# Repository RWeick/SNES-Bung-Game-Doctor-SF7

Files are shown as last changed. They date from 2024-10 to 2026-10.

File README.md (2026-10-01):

# SNES-Bung-Game-Doctor-SF7
The Kicad files and rom for the Bung Game Doctor SF7 for the SNES

This board has been tested and confirmed.
**30 Sep 2026: Thank you to CoolChecker for discovering that somehow a net failed to be connected - TC was not routed from the ASIC to the Floppy Controller. This has now been corrected.

Mainboard PCB Thickness: 1.6 mm
RAM PCB Thicknesses: 1.2 mm
SNES Attachment PCB Thickness: 1.2 mm

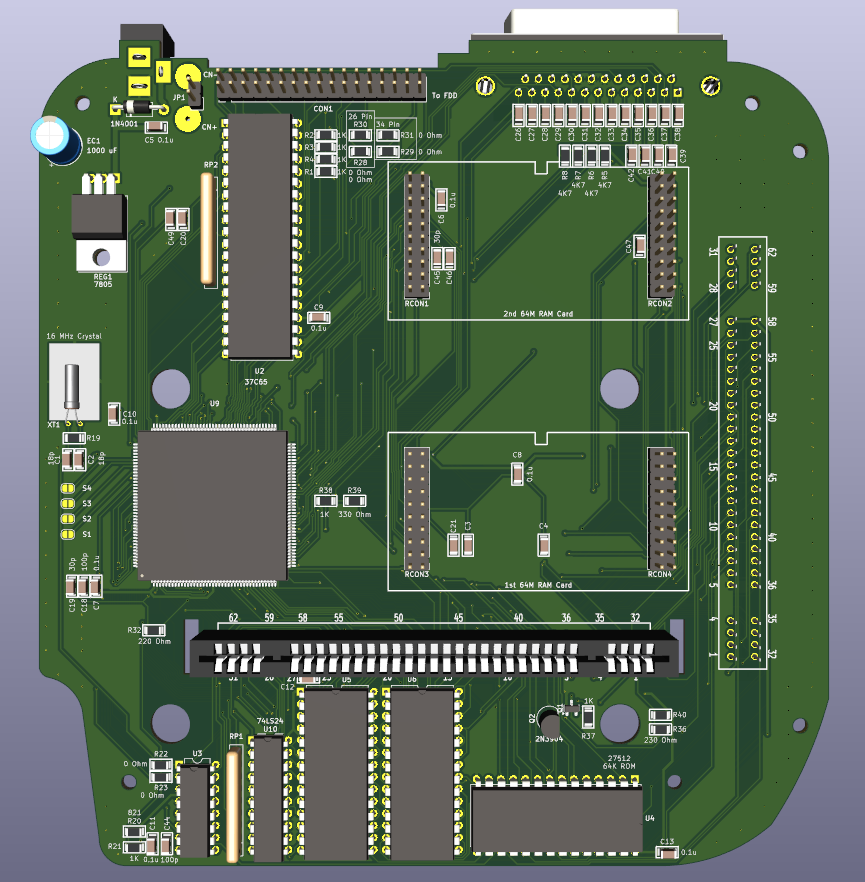
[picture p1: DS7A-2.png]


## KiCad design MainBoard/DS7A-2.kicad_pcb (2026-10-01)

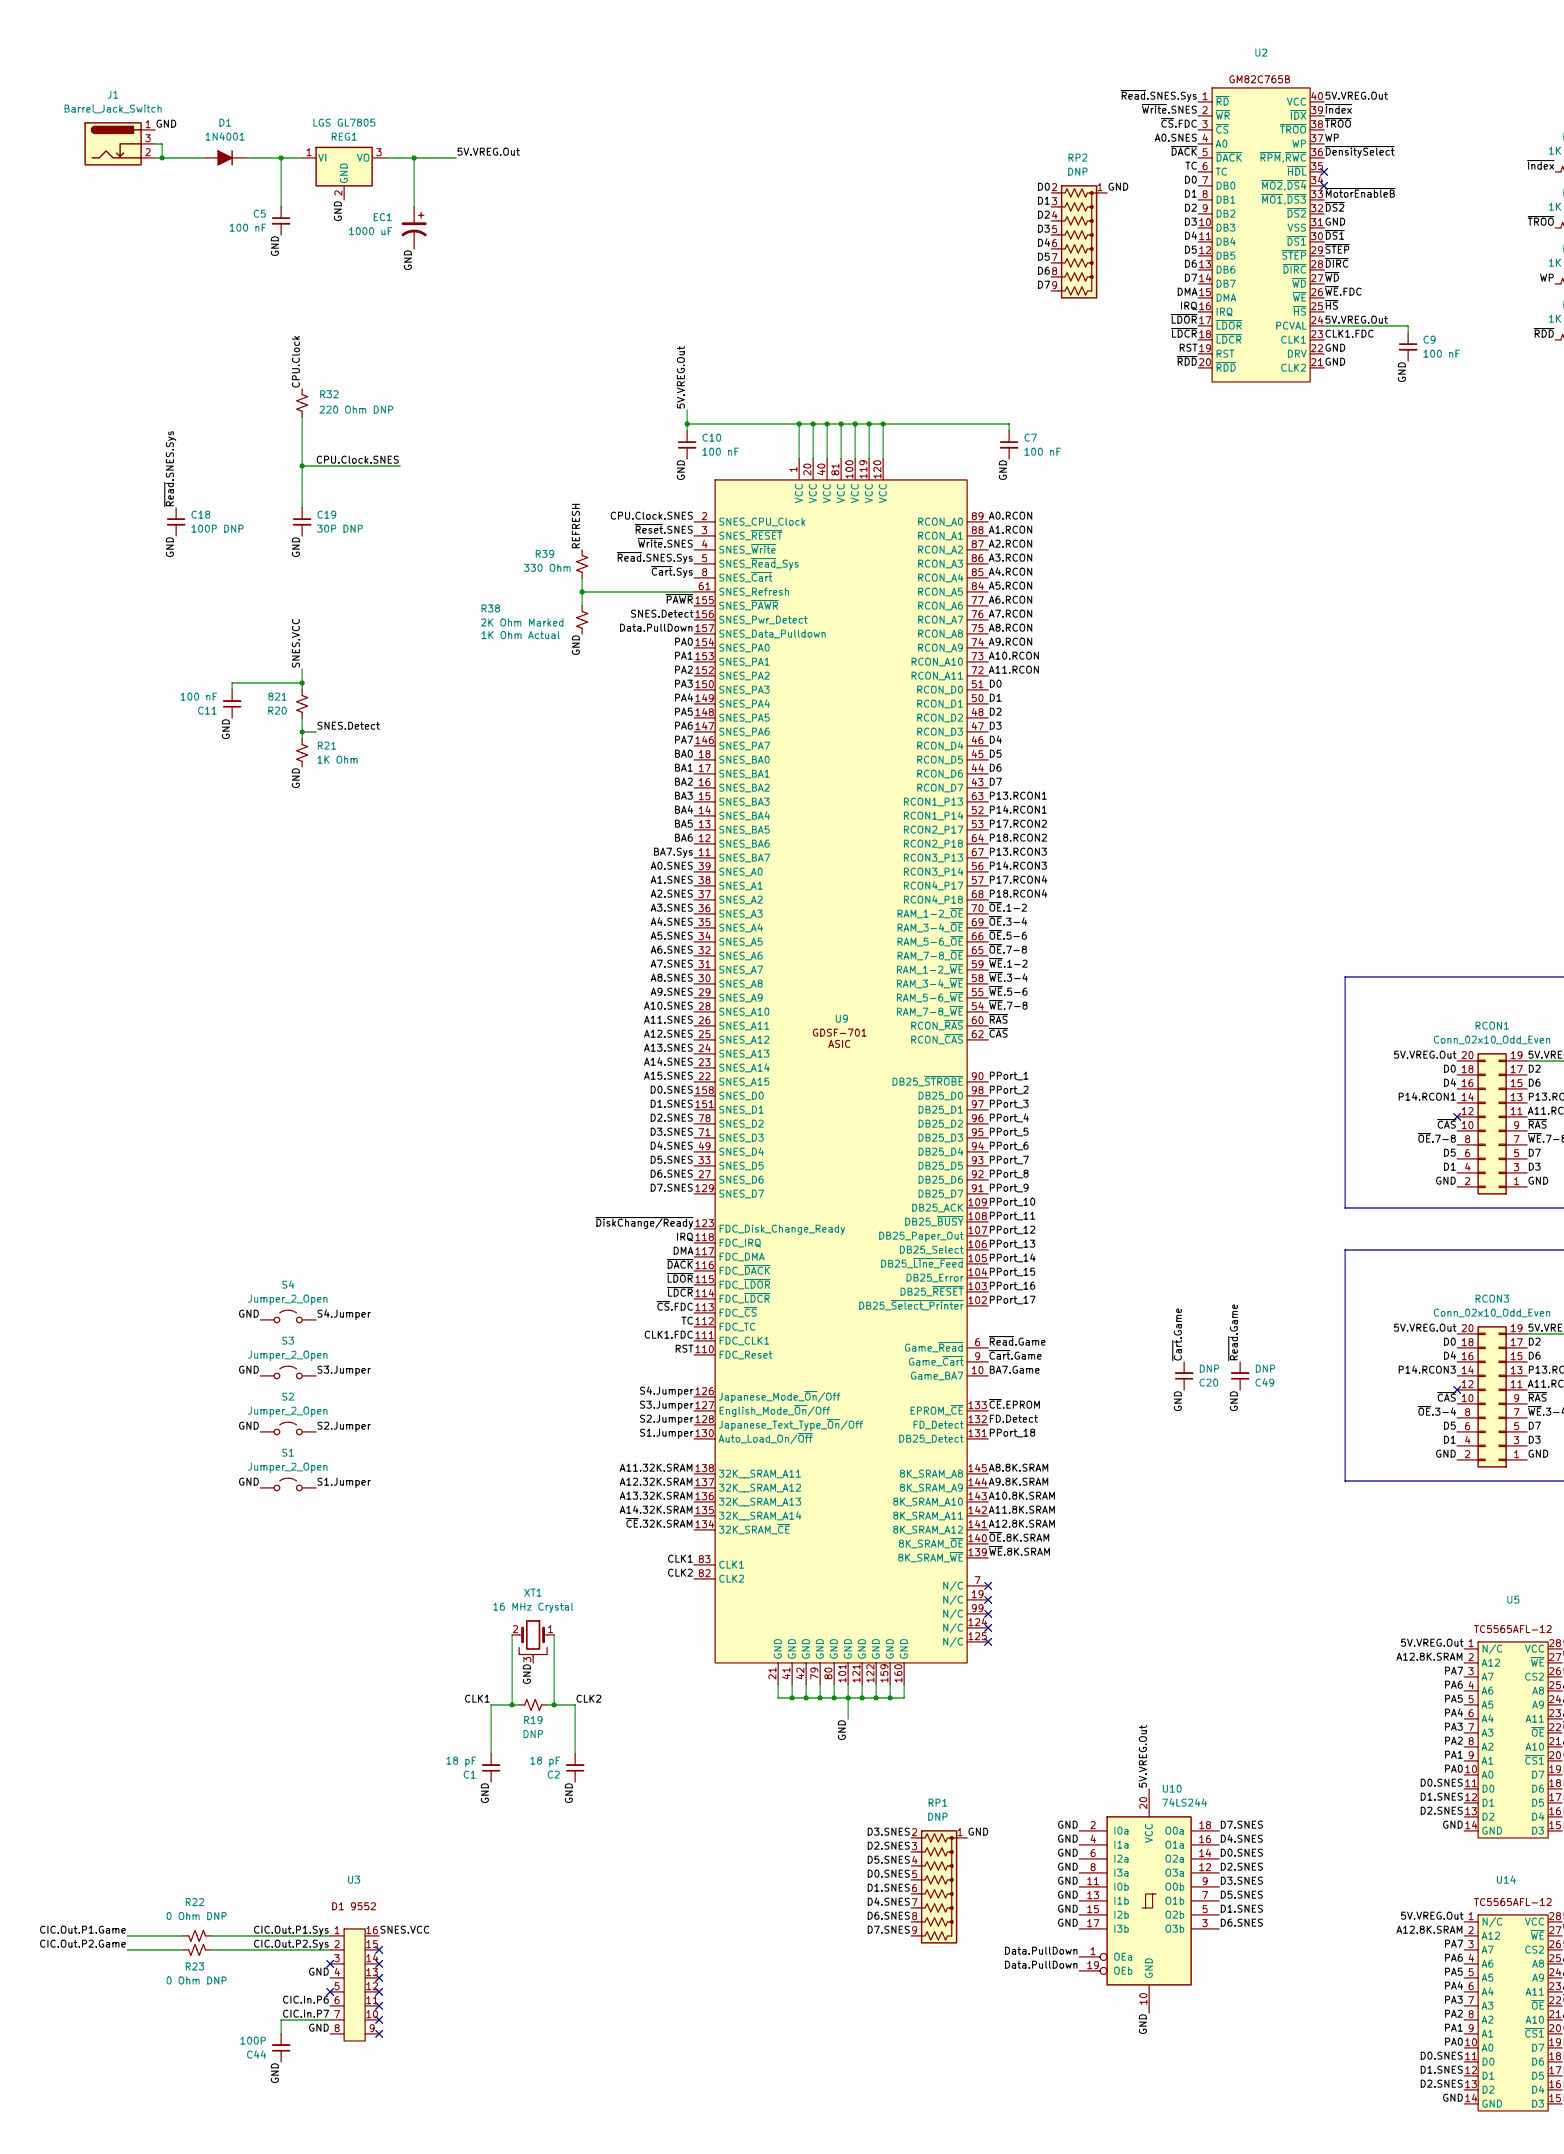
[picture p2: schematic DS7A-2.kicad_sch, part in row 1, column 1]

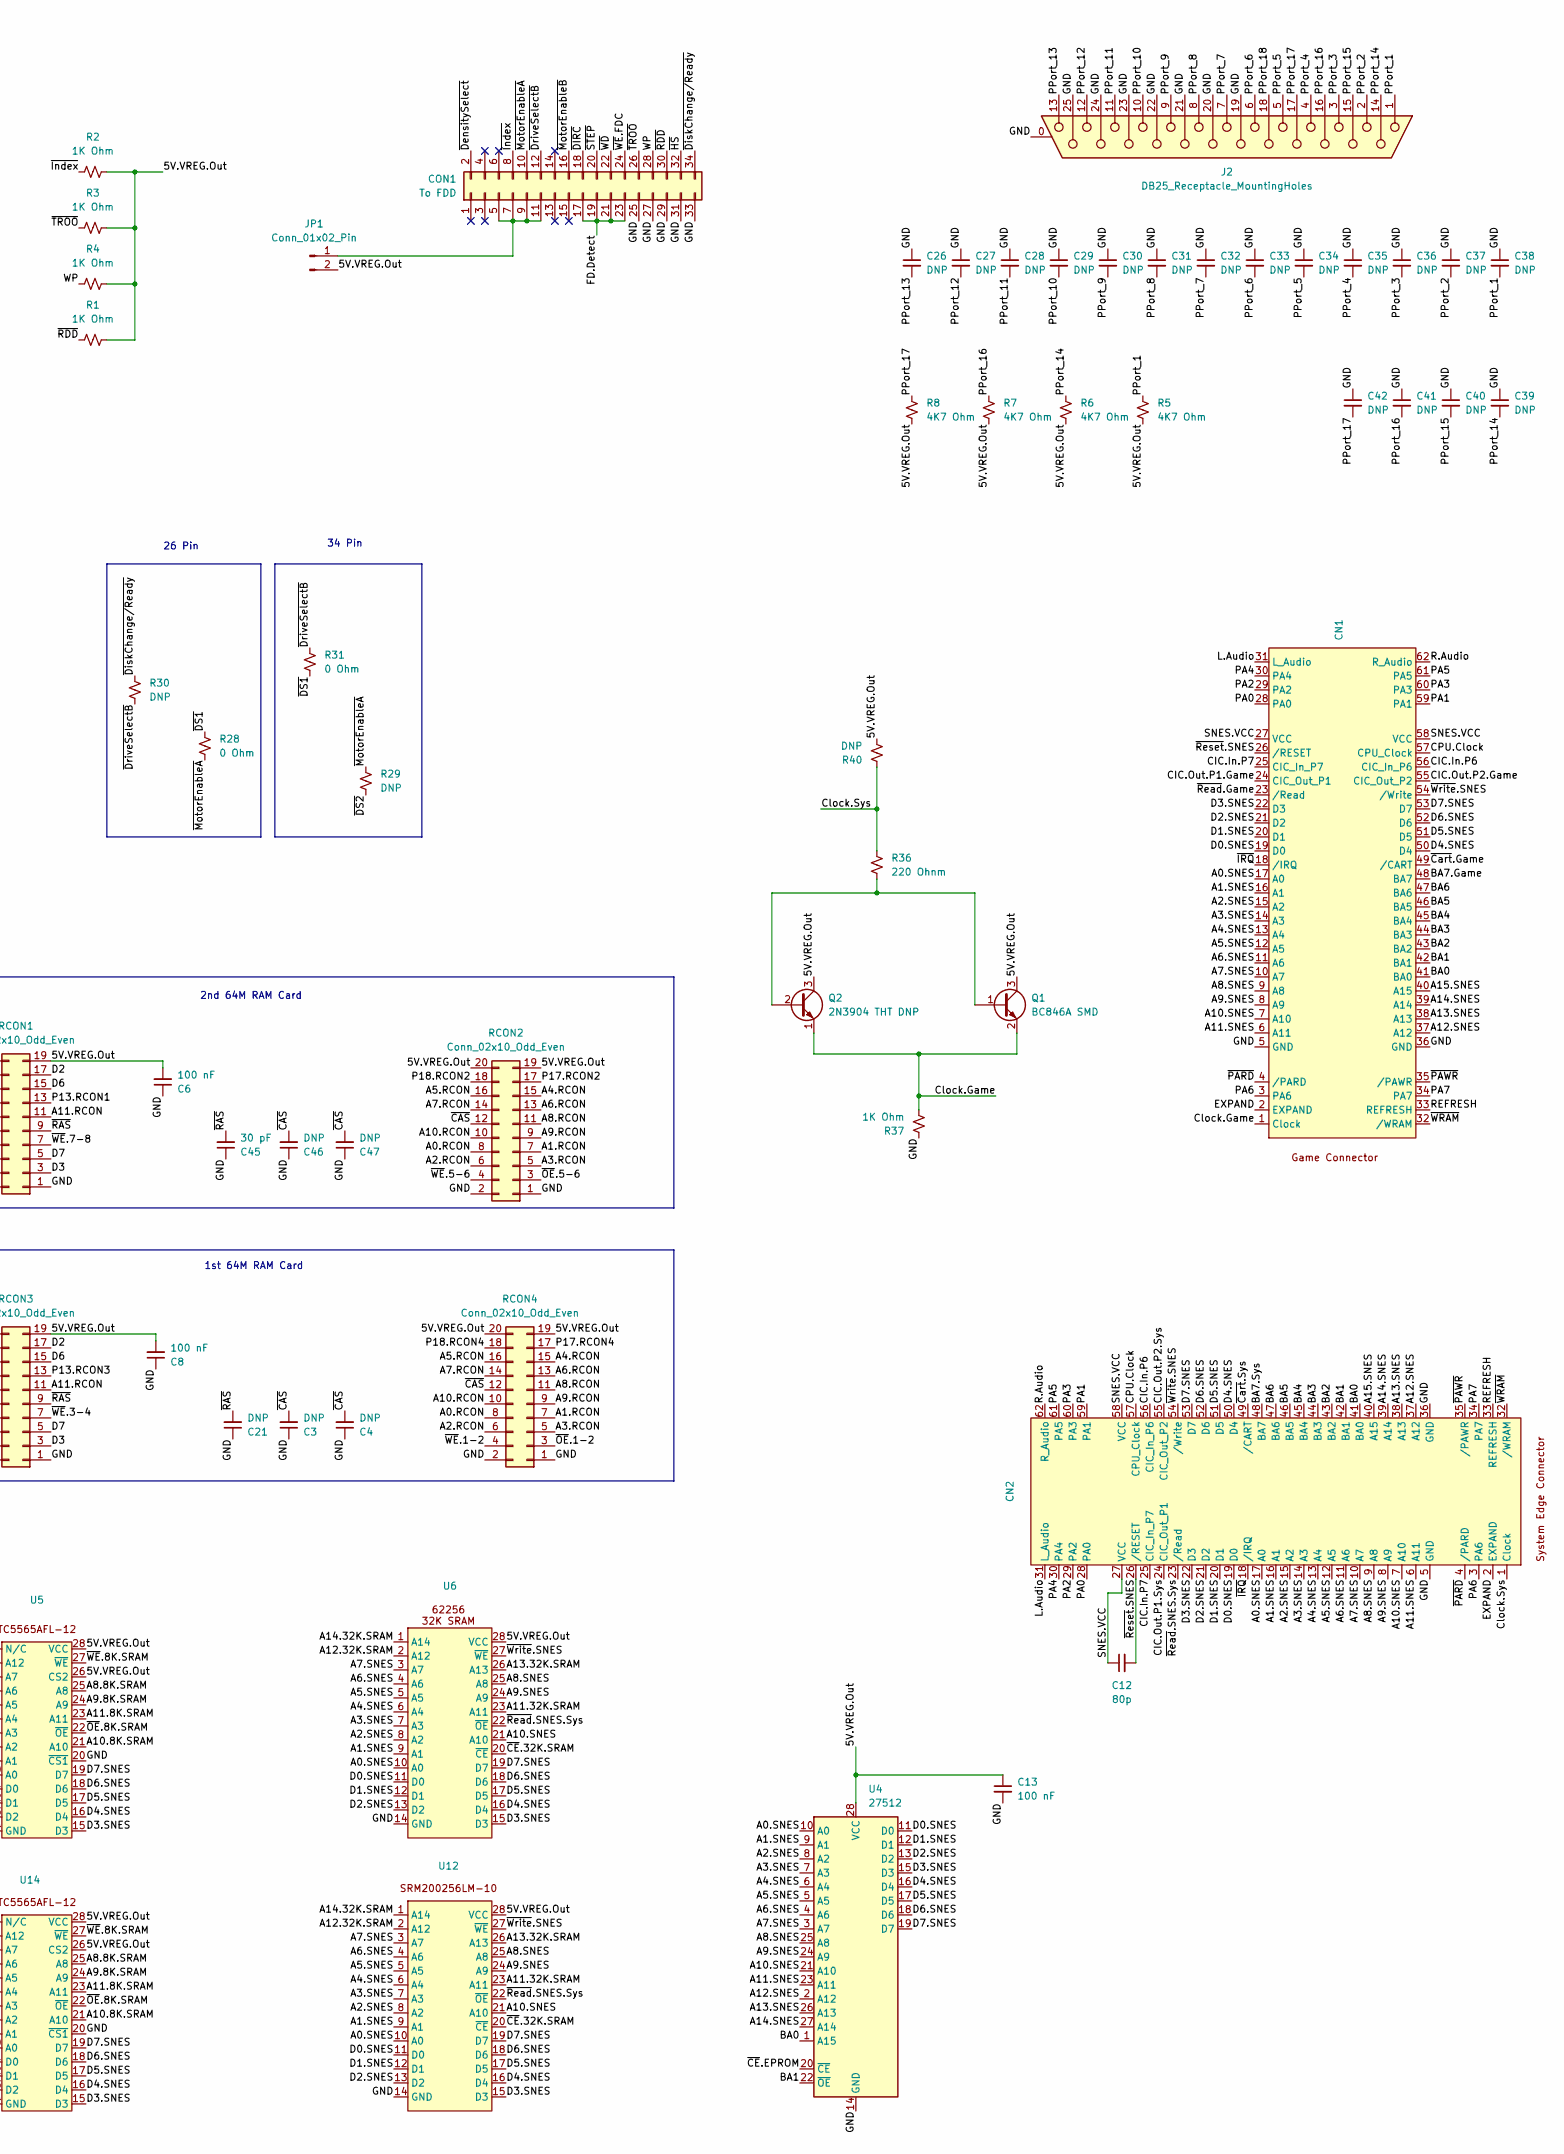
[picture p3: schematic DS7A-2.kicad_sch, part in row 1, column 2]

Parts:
C1, C2: 18 pF; SMD Cap
C3, C4, C20, C21, C26, C27, C28, C29, C30, C31, C32, C33, C34, C35, C36, C37, C38, C39, C40, C41, C42, C46, C47, C49: DNP; SMD Cap
C5, C6, C7, C8, C9, C10, C11, C13: 100 nF; SMD Cap
C12: 80p; SMD Cap
C18: 100P DNP; SMD Cap
C19: 30P DNP; SMD Cap
C44: 100P; SMD Cap
C45: 30 pF; SMD Cap
CN1, CN2: Cartridge Slot
CON1: To FDD; PinSocket_2x17_P2.54mm_Vertical
D1: 1N4001; D_DO-41_SOD81_P10.16mm_Horizontal
EC1: 1000 uF; CP_Radial_D8.0mm_P3.50mm
J1: Barrel_Jack_Switch; DC Jack
J2: DB25_Receptacle_MountingHoles; DSUB-25_Female_Horizontal_P2.77x2.84mm_EdgePinOffset9.90mm_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
JP1: Conn_01x02_Pin; PinHeader_1x02_P2.54mm_Vertical
Q1: BC846A SMD; SOT-23
Q2: 2N3904 THT DNP; TO-92_Inline
R1, R2, R3, R4, R21, R37: 1K Ohm; SMD Resistor
R5, R6, R7, R8: 4K7 Ohm; SMD Resistor
R19, R29, R30, R40: DNP; SMD Resistor
R20: 821; SMD Resistor
R22, R23: 0 Ohm DNP; SMD Resistor
R28, R31: 0 Ohm; SMD Resistor
R32: 220 Ohm DNP; SMD Resistor
R36: 220 Ohnm; SMD Resistor
R38: 2K Ohm Marked; SMD Resistor
R39: 330 Ohm; SMD Resistor
RCON1, RCON2, RCON3, RCON4: Conn_02x10_Odd_Even; PinHeader_2x10_P2.54mm_Vertical
REG1: LGS GL7805; TO-220-3_Vertical
RP1, RP2: DNP; R_Array_SIP9
S1, S2, S3, S4: Jumper_2_Open; SolderJumper-2_P1.3mm_Open_RoundedPad1.0x1.5mm
U2: DIP-40_W15.24mm
U3: DIP-16_W7.62mm
U4: 27512; DIP-28_W15.24mm
U5, U6: DIP-28_W15.24mm
U9: GDSF-701
U10: 74LS244; DIP-20_W7.62mm
U12, U14: SOP-28_8.4x18.16mm_P1.27mm
XT1: 16 MHz Crystal; Crystal_AT310_D3.0mm_L10.0mm_Horizontal_1EP_style1

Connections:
/5V.VREG.Out: C6.2, C7.1, C8.2, C9.1, C10.1, C13.1, EC1.1, JP1.2, Q1.3 (C), Q2.3 (C), R1.2, R2.2, R3.2, R4.2, R5.2, R6.2, R7.2, R8.2, R40.2, RCON1.19, RCON1.20, RCON2.19, RCON2.20, RCON3.19, RCON3.20, RCON4.19, RCON4.20, REG1.3 (VO), U2.24 (PCVAL), U2.40 (VCC), U4.28 (VCC), U5.1 (N/C), U5.26 (CS2), U5.28 (VCC), U6.28 (VCC), U9.1 (VCC), U9.20 (VCC), U9.40 (VCC), U9.81 (VCC), U9.100 (VCC), U9.119 (VCC), U9.120 (VCC), U10.20 (VCC), U12.28 (VCC), U14.1 (N/C), U14.26 (CS2), U14.28 (VCC)
/A0.RCON: RCON2.8, RCON4.8, U9.89 (RCON_A0)
/A0.SNES: CN1.17 (A0), CN2.17 (A0), U2.4 (A0), U4.10 (A0), U6.10 (A0), U9.39 (SNES_A0), U12.10 (A0)
/A1.RCON: RCON2.7, RCON4.7, U9.88 (RCON_A1)
/A1.SNES: CN1.16 (A1), CN2.16 (A1), U4.9 (A1), U6.9 (A1), U9.38 (SNES_A1), U12.9 (A1)
/A2.RCON: RCON2.6, RCON4.6, U9.87 (RCON_A2)
/A2.SNES: CN1.15 (A2), CN2.15 (A2), U4.8 (A2), U6.8 (A2), U9.37 (SNES_A2), U12.8 (A2)
/A3.RCON: RCON2.5, RCON4.5, U9.86 (RCON_A3)
/A3.SNES: CN1.14 (A3), CN2.14 (A3), U4.7 (A3), U6.7 (A3), U9.36 (SNES_A3), U12.7 (A3)
/A4.RCON: RCON2.15, RCON4.15, U9.85 (RCON_A4)
/A4.SNES: CN1.13 (A4), CN2.13 (A4), U4.6 (A4), U6.6 (A4), U9.35 (SNES_A4), U12.6 (A4)
/A5.RCON: RCON2.16, RCON4.16, U9.84 (RCON_A5)
/A5.SNES: CN1.12 (A5), CN2.12 (A5), U4.5 (A5), U6.5 (A5), U9.34 (SNES_A5), U12.5 (A5)
/A6.RCON: RCON2.13, RCON4.13, U9.77 (RCON_A6)
/A6.SNES: CN1.11 (A6), CN2.11 (A6), U4.4 (A6), U6.4 (A6), U9.32 (SNES_A6), U12.4 (A6)
/A7.RCON: RCON2.14, RCON4.14, U9.76 (RCON_A7)
/A7.SNES: CN1.10 (A7), CN2.10 (A7), U4.3 (A7), U6.3 (A7), U9.31 (SNES_A7), U12.3 (A7)
/A8.8K.SRAM: U5.25 (A8), U9.145 (8K_SRAM_A8), U14.25 (A8)
/A8.RCON: RCON2.11, RCON4.11, U9.75 (RCON_A8)
/A8.SNES: CN1.9 (A8), CN2.9 (A8), U4.25 (A8), U6.25 (A8), U9.30 (SNES_A8), U12.25 (A8)
/A9.8K.SRAM: U5.24 (A9), U9.144 (8K_SRAM_A9), U14.24 (A9)
/A9.RCON: RCON2.9, RCON4.9, U9.74 (RCON_A9)
/A9.SNES: CN1.8 (A9), CN2.8 (A9), U4.24 (A9), U6.24 (A9), U9.29 (SNES_A9), U12.24 (A9)
/A10.8K.SRAM: U5.21 (A10), U9.143 (8K_SRAM_A10), U14.21 (A10)
/A10.RCON: RCON2.10, RCON4.10, U9.73 (RCON_A10)
/A10.SNES: CN1.7 (A10), CN2.7 (A10), U4.21 (A10), U6.21 (A10), U9.28 (SNES_A10), U12.21 (A10)
/A11.8K.SRAM: U5.23 (A11), U9.142 (8K_SRAM_A11), U14.23 (A11)
/A11.32K.SRAM: U6.23 (A11), U9.138 (32K__SRAM_A11), U12.23 (A11)
/A11.RCON: RCON1.11, RCON3.11, U9.72 (RCON_A11)
/A11.SNES: CN1.6 (A11), CN2.6 (A11), U4.23 (A11), U9.26 (SNES_A11)
/A12.8K.SRAM: U5.2 (A12), U9.141 (8K_SRAM_A12), U14.2 (A12)
/A12.32K.SRAM: U6.2 (A12), U9.137 (32K__SRAM_A12), U12.2 (A12)
/A12.SNES: CN1.37 (A12), CN2.37 (A12), U4.2 (A12), U9.25 (SNES_A12)
/A13.32K.SRAM: U6.26 (A13), U9.136 (32K__SRAM_A13), U12.26 (A13)
/A13.SNES: CN1.38 (A13), CN2.38 (A13), U4.26 (A13), U9.24 (SNES_A13)
/A14.32K.SRAM: U6.1 (A14), U9.135 (32K__SRAM_A14), U12.1 (A14)
/A14.SNES: CN1.39 (A14), CN2.39 (A14), U4.27 (A14), U9.23 (SNES_A14)
/A15.SNES: CN1.40 (A15), CN2.40 (A15), U9.22 (SNES_A15)
/BA0: CN1.41 (BA0), CN2.41 (BA0), U4.1 (A15), U9.18 (SNES_BA0)
/BA1: CN1.42 (BA1), CN2.42 (BA1), U4.22 (~OE), U9.17 (SNES_BA1)
/BA2: CN1.43 (BA2), CN2.43 (BA2), U9.16 (SNES_BA2)
/BA3: CN1.44 (BA3), CN2.44 (BA3), U9.15 (SNES_BA3)
/BA4: CN1.45 (BA4), CN2.45 (BA4), U9.14 (SNES_BA4)
/BA5: CN1.46 (BA5), CN2.46 (BA5), U9.13 (SNES_BA5)
/BA6: CN1.47 (BA6), CN2.47 (BA6), U9.12 (SNES_BA6)
/BA7.Game: CN1.48 (BA7), U9.10 (Game_BA7)
/BA7.Sys: CN2.48 (BA7), U9.11 (SNES_BA7)
/CIC.In.P6: CN1.56 (CIC_In_P6), CN2.56 (CIC_In_P6), U3.6
/CIC.In.P7: C44.2, CN1.25 (CIC_In_P7), CN2.25 (CIC_In_P7), U3.7
/CIC.Out.P1.Game: CN1.24 (CIC_Out_P1), R22.1
/CIC.Out.P1.Sys: CN2.24 (CIC_Out_P1), R22.2, U3.1
/CIC.Out.P2.Game: CN1.55 (CIC_Out_P2), R23.1
/CIC.Out.P2.Sys: CN2.55 (CIC_Out_P2), R23.2, U3.2
/CLK1: C1.2, R19.1, U9.83 (CLK1), XT1.2
/CLK1.FDC: U2.23 (CLK1), U9.111 (FDC_CLK1)
/CLK2: C2.2, R19.2, U9.82 (CLK2), XT1.1
/CPU.Clock: CN1.57 (CPU_Clock), CN2.57 (CPU_Clock), R32.2
/CPU.Clock.SNES: C19.1, R32.1, U9.2 (SNES_CPU_Clock)
/Clock.Game: CN1.1 (Clock), Q1.2 (E), Q2.1 (E), R37.2
/Clock.Sys: CN2.1 (Clock), R36.1, R40.1
/D0: RCON1.18, RCON3.18, RP2.2 (R1), U2.7 (DB0), U9.51 (RCON_D0)
/D0.SNES: CN1.19 (D0), CN2.19 (D0), RP1.5 (R4), U4.11 (D0), U5.11 (D0), U6.11 (D0), U9.158 (SNES_D0), U10.14 (O2a), U12.11 (D0), U14.11 (D0)
/D1: RCON1.4, RCON3.4, RP2.3 (R2), U2.8 (DB1), U9.50 (RCON_D1)
/D1.SNES: CN1.20 (D1), CN2.20 (D1), RP1.6 (R5), U4.12 (D1), U5.12 (D1), U6.12 (D1), U9.151 (SNES_D1), U10.5 (O2b), U12.12 (D1), U14.12 (D1)
/D2: RCON1.17, RCON3.17, RP2.4 (R3), U2.9 (DB2), U9.48 (RCON_D2)
/D2.SNES: CN1.21 (D2), CN2.21 (D2), RP1.3 (R2), U4.13 (D2), U5.13 (D2), U6.13 (D2), U9.78 (SNES_D2), U10.12 (O3a), U12.13 (D2), U14.13 (D2)
/D3: RCON1.3, RCON3.3, RP2.5 (R4), U2.10 (DB3), U9.47 (RCON_D3)
/D3.SNES: CN1.22 (D3), CN2.22 (D3), RP1.2 (R1), U4.15 (D3), U5.15 (D3), U6.15 (D3), U9.71 (SNES_D3), U10.9 (O0b), U12.15 (D3), U14.15 (D3)
/D4: RCON1.16, RCON3.16, RP2.6 (R5), U2.11 (DB4), U9.46 (RCON_D4)
/D4.SNES: CN1.50 (D4), CN2.50 (D4), RP1.7 (R6), U4.16 (D4), U5.16 (D4), U6.16 (D4), U9.49 (SNES_D4), U10.16 (O1a), U12.16 (D4), U14.16 (D4)
/D5: RCON1.6, RCON3.6, RP2.7 (R6), U2.12 (DB5), U9.45 (RCON_D5)
/D5.SNES: CN1.51 (D5), CN2.51 (D5), RP1.4 (R3), U4.17 (D5), U5.17 (D5), U6.17 (D5), U9.33 (SNES_D5), U10.7 (O1b), U12.17 (D5), U14.17 (D5)
/D6: RCON1.15, RCON3.15, RP2.8 (R7), U2.13 (DB6), U9.44 (RCON_D6)
/D6.SNES: CN1.52 (D6), CN2.52 (D6), RP1.8 (R7), U4.18 (D6), U5.18 (D6), U6.18 (D6), U9.27 (SNES_D6), U10.3 (O3b), U12.18 (D6), U14.18 (D6)
/D7: RCON1.5, RCON3.5, RP2.9 (R8), U2.14 (DB7), U9.43 (RCON_D7)
/D7.SNES: CN1.53 (D7), CN2.53 (D7), RP1.9 (R8), U4.19 (D7), U5.19 (D7), U6.19 (D7), U9.129 (SNES_D7), U10.18 (O0a), U12.19 (D7), U14.19 (D7)
/DMA: U2.15 (DMA), U9.117 (FDC_DMA)
/Data.PullDown: U9.157 (SNES_Data_Pulldown), U10.1 (OEa), U10.19 (OEb)
/EXPAND: CN1.2 (EXPAND), CN2.2 (EXPAND)
/FD.Detect: CON1.17, CON1.19, CON1.21, CON1.23, U9.132 (FD_Detect)
/GND: C1.1, C2.1, C3.1, C4.1, C5.2, C6.1, C7.2, C8.1, C9.2, C10.2, C11.1, C13.2, C18.2, C19.2, C20.1, C21.1, C26.1, C27.1, C28.1, C29.1, C30.1, C31.1, C32.1, C33.1, C34.1, C35.1, C36.1, C37.1, C38.1, C39.1, C40.1, C41.1, C42.1, C44.1, C45.1, C46.1, C47.1, C49.1, CN1.5 (GND), CN1.36 (GND), CN2.5 (GND), CN2.36 (GND), CON1.25, CON1.27, CON1.29, CON1.31, CON1.33, EC1.2, J1.1, J2.0 (PAD), J2.19, J2.20, J2.21, J2.22, J2.23, J2.24, J2.25, R21.2, R37.1, R38.1, RCON1.1, RCON1.2, RCON2.1, RCON2.2, RCON3.1, RCON3.2, RCON4.1, RCON4.2, REG1.2 (GND), RP1.1 (common), RP2.1 (common), S1.1 (A), S2.1 (A), S3.1 (A), S4.1 (A), U2.21 (CLK2), U2.22 (DRV), U2.31 (VSS), U3.4, U3.8, U4.14 (GND), U5.14 (GND), U5.20 (~CS1), U6.14 (GND), U9.21 (GND), U9.41 (GND), U9.42 (GND), U9.79 (GND), U9.80 (GND), U9.101 (GND), U9.121 (GND), U9.122 (GND), U9.159 (GND), U9.160 (GND), U10.2 (I0a), U10.4 (I1a), U10.6 (I2a), U10.8 (I3a), U10.10 (GND), U10.11 (I0b), U10.13 (I1b), U10.15 (I2b), U10.17 (I3b), U12.14 (GND), U14.14 (GND), U14.20 (~CS1), XT1.3
/IRQ: U2.16 (IRQ), U9.118 (FDC_IRQ)
/L.Audio: CN1.31 (L_Audio), CN2.31 (L_Audio)
/P13.RCON1: RCON1.13, U9.63 (RCON1_P13)
/P13.RCON3: RCON3.13, U9.67 (RCON3_P13)
/P14.RCON1: RCON1.14, U9.52 (RCON1_P14)
/P14.RCON3: RCON3.14, U9.56 (RCON3_P14)
/P17.RCON2: RCON2.17, U9.53 (RCON2_P17)
/P17.RCON4: RCON4.17, U9.57 (RCON4_P17)
/P18.RCON2: RCON2.18, U9.64 (RCON2_P18)
/P18.RCON4: RCON4.18, U9.68 (RCON4_P18)
/PA0: CN1.28 (PA0), CN2.28 (PA0), U5.10 (A0), U9.154 (SNES_PA0), U14.10 (A0)
/PA1: CN1.59 (PA1), CN2.59 (PA1), U5.9 (A1), U9.153 (SNES_PA1), U14.9 (A1)
/PA2: CN1.29 (PA2), CN2.29 (PA2), U5.8 (A2), U9.152 (SNES_PA2), U14.8 (A2)
/PA3: CN1.60 (PA3), CN2.60 (PA3), U5.7 (A3), U9.150 (SNES_PA3), U14.7 (A3)
/PA4: CN1.30 (PA4), CN2.30 (PA4), U5.6 (A4), U9.149 (SNES_PA4), U14.6 (A4)
/PA5: CN1.61 (PA5), CN2.61 (PA5), U5.5 (A5), U9.148 (SNES_PA5), U14.5 (A5)
/PA6: CN1.3 (PA6), CN2.3 (PA6), U5.4 (A6), U9.147 (SNES_PA6), U14.4 (A6)
/PA7: CN1.34 (PA7), CN2.34 (PA7), U5.3 (A7), U9.146 (SNES_PA7), U14.3 (A7)
/PPort_1: C38.2, J2.1, R5.1, U9.90 (DB25_~STROBE)
/PPort_2: C37.2, J2.2, U9.98 (DB25_D0)
/PPort_3: C36.2, J2.3, U9.97 (DB25_D1)
/PPort_4: C35.2, J2.4, U9.96 (DB25_D2)
/PPort_5: C34.2, J2.5, U9.95 (DB25_D3)
/PPort_6: C33.2, J2.6, U9.94 (DB25_D4)
/PPort_7: C32.2, J2.7, U9.93 (DB25_D5)
/PPort_8: C31.2, J2.8, U9.92 (DB25_D6)
/PPort_9: C30.2, J2.9, U9.91 (DB25_D7)
/PPort_10: C29.2, J2.10, U9.109 (DB25_ACK)
/PPort_11: C28.2, J2.11, U9.108 (DB25_~BUSY)
/PPort_12: C27.2, J2.12, U9.107 (DB25_Paper_Out)
/PPort_13: C26.2, J2.13, U9.106 (DB25_Select)
/PPort_14: C39.2, J2.14, R6.1, U9.105 (DB25_~Line_Feed)
/PPort_15: C40.2, J2.15, U9.104 (DB25_Error)
/PPort_16: C41.2, J2.16, R7.1, U9.103 (DB25_~RESET)
/PPort_17: C42.2, J2.17, R8.1, U9.102 (DB25_~Select_Printer)
/PPort_18: J2.18, U9.131 (DB25_Detect)
/R.Audio: CN1.62 (R_Audio), CN2.62 (R_Audio)
/REFRESH: CN1.33 (REFRESH), CN2.33 (REFRESH), R39.2
/RST: U2.19 (RST), U9.110 (FDC_Reset)
/S1.Jumper: S1.2 (B), U9.130 (Auto_Load_On/~Off)
/S2.Jumper: S2.2 (B), U9.128 (Japanese_Text_Type_~On/Off)
/S3.Jumper: S3.2 (B), U9.127 (English_Mode_~On/Off)
/S4.Jumper: S4.2 (B), U9.126 (Japanese_Mode_~On/Off)
/SNES.Detect: R20.1, R21.1, U9.156 (SNES_Pwr_Detect)
/SNES.VCC: C11.2, C12.1, CN1.27 (VCC), CN1.58 (VCC), CN2.27 (VCC), CN2.58 (VCC), R20.2, U3.16
/TC: U2.6 (TC), U9.112 (FDC_TC)
/WP: CON1.28, R4.1, U2.37 (WP)
/~CAS: C3.2, C4.2, C46.2, C47.2, RCON1.10, RCON2.12, RCON3.10, RCON4.12, U9.62 (RCON_~CAS)
/~CE.32K.SRAM: U6.20 (~CE), U9.134 (32K_SRAM_~CE), U12.20 (~CE)
/~CE.EPROM: U4.20 (~CE), U9.133 (EPROM_~CE)
/~CS.FDC: U2.3 (~CS), U9.113 (FDC_~CS)
/~Cart.Game: C20.2, CN1.49 (/CART), U9.9 (Game_~Cart)
/~Cart.Sys: CN2.49 (/CART), U9.8 (SNES_~Cart)
/~DACK: U2.5 (~DACK), U9.116 (FDC_~DACK)
/~DIRC: CON1.18, U2.28 (~DIRC)
/~DS1: R28.1, R31.2, U2.30 (~DS1)
/~DS2: R29.2, U2.32 (~DS2)
/~DensitySelect: CON1.2, U2.36 (~RPM,~RWC)
/~DiskChange/Ready: CON1.34, R30.1, U9.123 (FDC_Disk_Change_Ready)
/~DriveSelectB: CON1.12, R30.2, R31.1
/~HS: CON1.32, U2.25 (~HS)
/~IRQ: CN1.18 (/IRQ), CN2.18 (/IRQ)
/~Index: CON1.8, R2.1, U2.39 (~IDX)
/~LDCR: U2.18 (~LDCR), U9.114 (FDC_~LDCR)
/~LDOR: U2.17 (~LDOR), U9.115 (FDC_~LDOR)
/~MotorEnableA: CON1.10, R28.2, R29.1
/~MotorEnableB: CON1.16, U2.33 (~MO1,~DS3)
/~OE.1-2: RCON4.3, U9.70 (RAM_1-2_~OE)
/~OE.3-4: RCON3.8, U9.69 (RAM_3-4_~OE)
/~OE.5-6: RCON2.3, U9.66 (RAM_5-6_~OE)
/~OE.7-8: RCON1.8, U9.65 (RAM_7-8_~OE)
/~OE.8K.SRAM: U5.22 (~OE), U9.140 (8K_SRAM_~OE), U14.22 (~OE)
/~PARD: CN1.4 (/PARD), CN2.4 (/PARD)
/~PAWR: CN1.35 (/PAWR), CN2.35 (/PAWR), U9.155 (SNES_~PAWR)
/~RAS: C21.2, C45.2, RCON1.9, RCON3.9, U9.60 (RCON_~RAS)
/~RDD: CON1.30, R1.1, U2.20 (~RDD)
/~Read.Game: C49.2, CN1.23 (/Read), U9.6 (Game_~Read)
/~Read.SNES.Sys: C18.1, CN2.23 (/Read), U2.1 (~RD), U6.22 (~OE), U9.5 (SNES_~Read_Sys), U12.22 (~OE)
/~Reset.SNES: C12.2, CN1.26 (/RESET), CN2.26 (/RESET), U9.3 (SNES_~RESET)
/~STEP: CON1.20, U2.29 (~STEP)
/~TROO: CON1.26, R3.1, U2.38 (~TROO)
/~WD: CON1.22, U2.27 (~WD)
/~WE.1-2: RCON4.4, U9.59 (RAM_1-2_~WE)
/~WE.3-4: RCON3.7, U9.58 (RAM_3-4_~WE)
/~WE.5-6: RCON2.4, U9.55 (RAM_5-6_~WE)
/~WE.7-8: RCON1.7, U9.54 (RAM_7-8_~WE)
/~WE.8K.SRAM: U5.27 (~WE), U9.139 (8K_SRAM_~WE), U14.27 (~WE)
/~WE.FDC: CON1.24, U2.26 (~WE)
/~WRAM: CN1.32 (/WRAM), CN2.32 (/WRAM)
/~Write.SNES: CN1.54 (/Write), CN2.54 (/Write), U2.2 (~WR), U6.27 (~WE), U9.4 (SNES_~Write), U12.27 (~WE)
unnamed: CON1.5, CON1.7, CON1.9, CON1.11, JP1.1
unnamed: D1.2 (A), J1.2, J1.3
unnamed: C5.1, D1.1 (K), REG1.1 (VI)
unnamed: Q1.1 (B), Q2.2 (B), R36.2
unnamed: R38.2, R39.1, U9.61 (SNES_Refresh)

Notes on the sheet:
34 Pin
1st 64M RAM Card
2nd 64M RAM Card
26 Pin

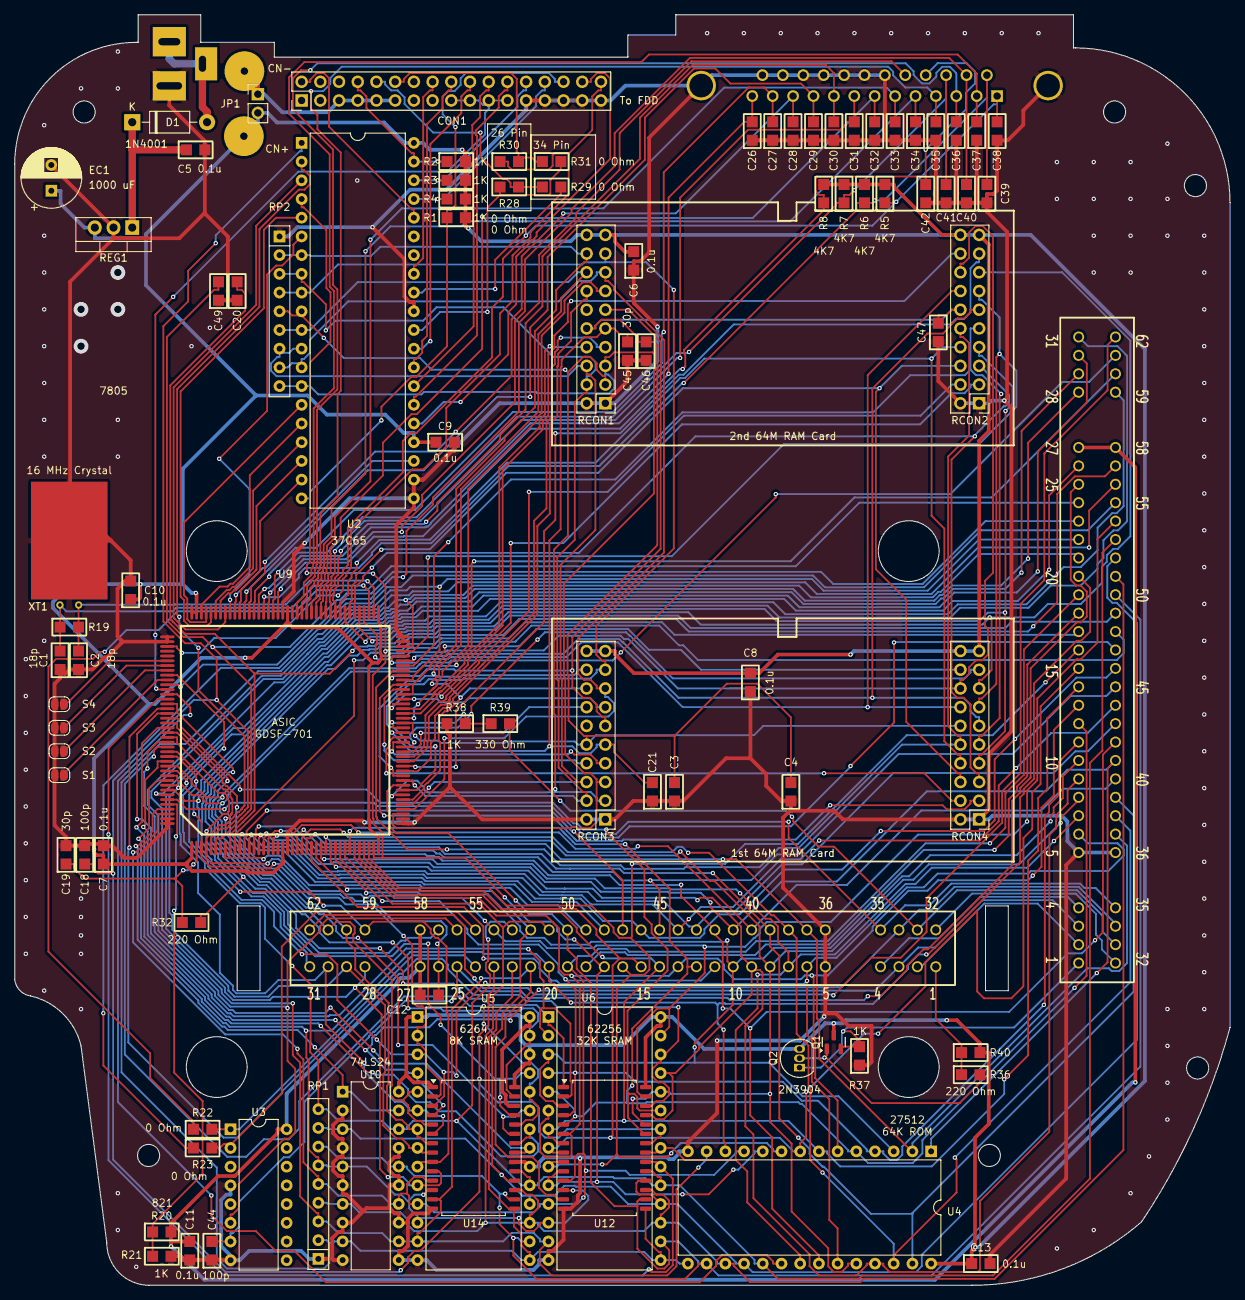
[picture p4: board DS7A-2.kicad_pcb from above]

Board: 2 copper layers, 165.0 x 172.5 mm, 93 parts (1 on the bottom side), 176 nets.

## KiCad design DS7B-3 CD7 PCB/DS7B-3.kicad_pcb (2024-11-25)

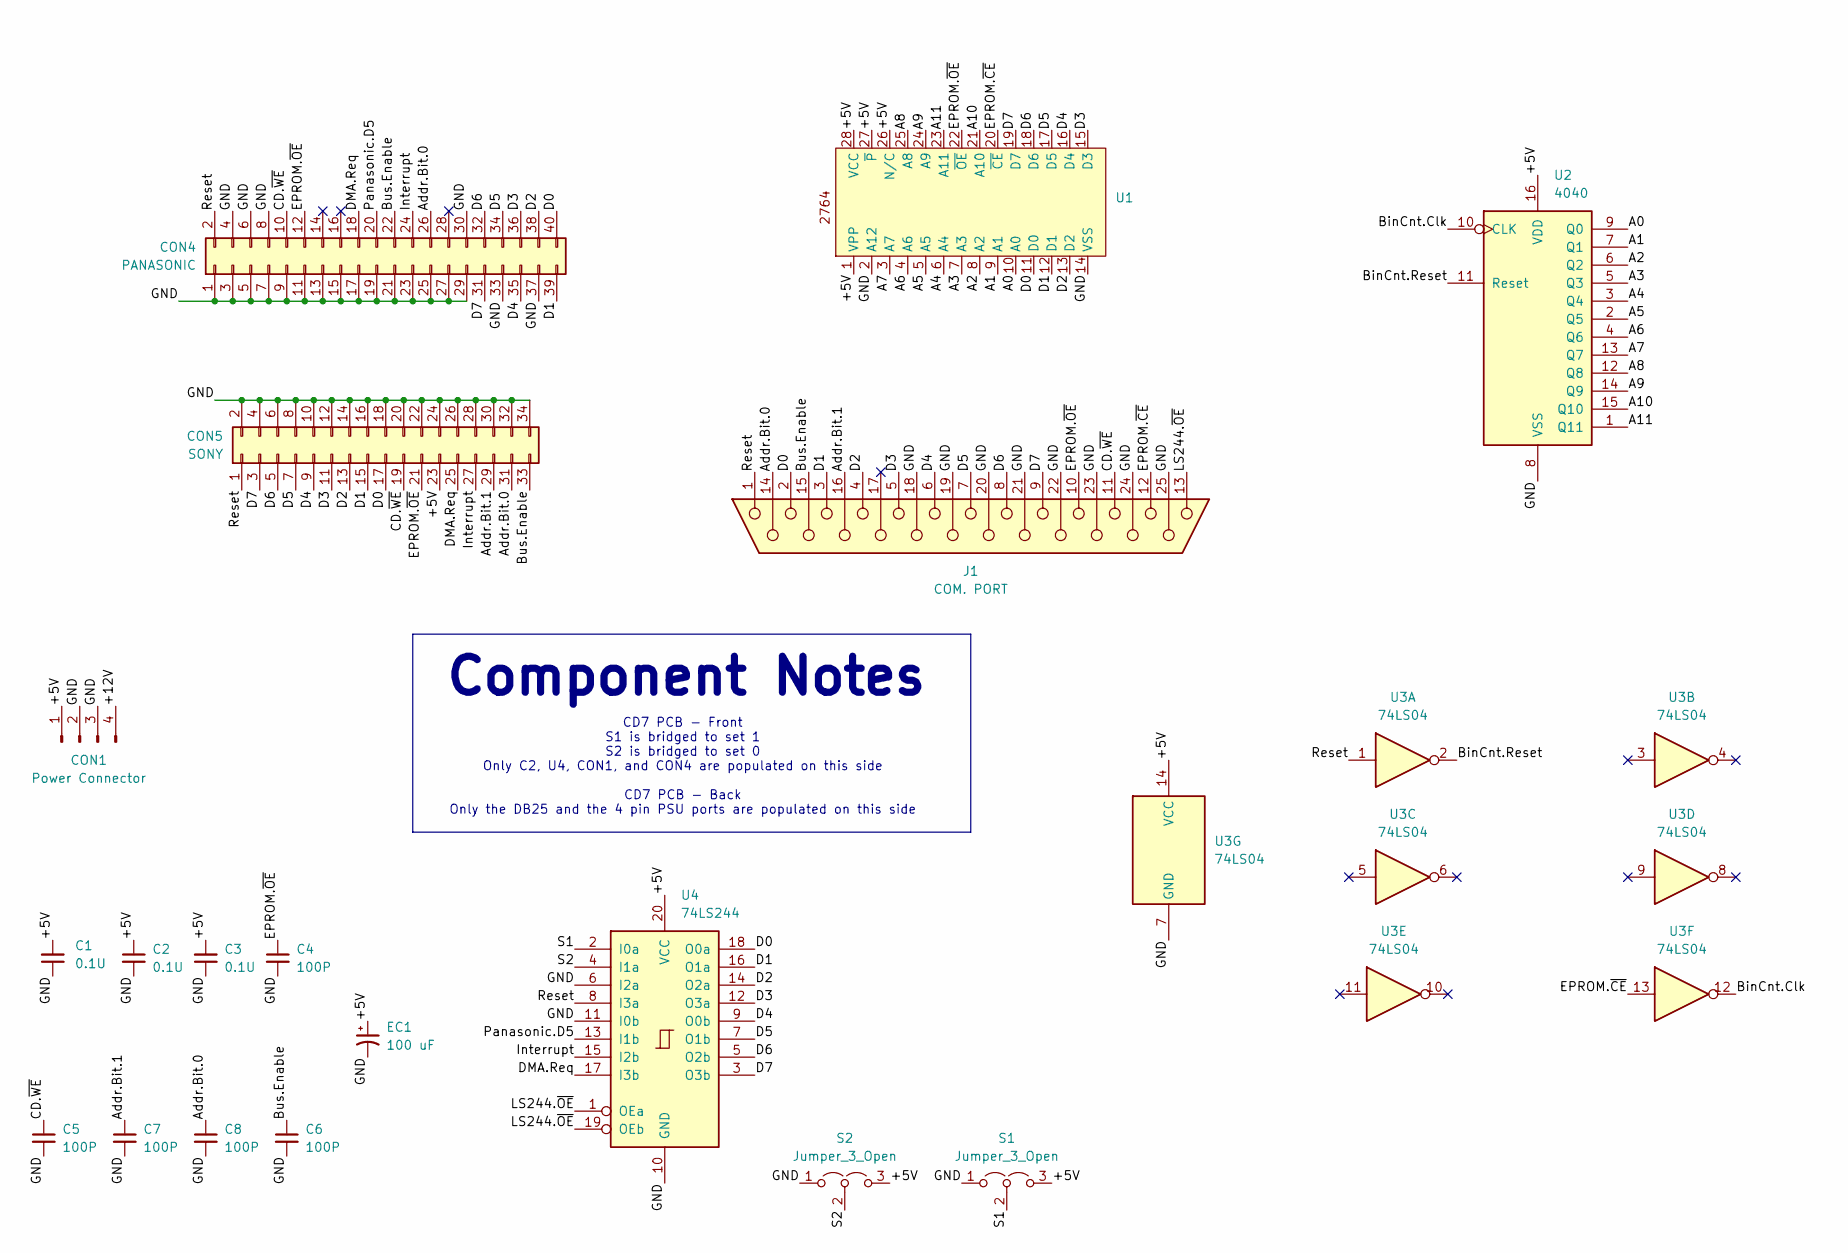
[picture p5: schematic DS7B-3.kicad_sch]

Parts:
C1, C2, C3: 0.1U; C_Disc_D5.0mm_W2.5mm_P5.00mm
C4, C5, C6, C7, C8: 100P; C_Disc_D3.8mm_W2.6mm_P2.50mm
CON1: Power Connector; Molex_KK-396_A-41791-0004_1x04_P3.96mm_Vertical
CON4: PANASONIC; IDC-Header_2x20_P2.54mm_Vertical
CON5: SONY; IDC-Header_2x17_P2.54mm_Vertical
EC1: 100 uF; CP_Radial_D8.0mm_P2.50mm
J1: COM. PORT; DSUB-25_Female_Vertical_P2.77x2.84mm_MountingHoles
S1, S2: Jumper_3_Open; PinHeader_1x03_P2.54mm_Vertical
U1: DIP-28_W15.24mm
U2: 4040; DIP-16_W7.62mm
U3: 74LS04; DIP-14_W7.62mm
U4: 74LS244; DIP-20_W7.62mm

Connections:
/+5V: C1.2, C2.1, C3.2, CON1.1, CON5.23, EC1.1, S1.3 (B), S2.3 (B), U1.1 (VPP), U1.26 (N/C), U1.27 (~P), U1.28 (VCC), U2.16 (VDD), U3.14 (VCC), U4.20 (VCC)
/+12V: CON1.4
/A0: U1.10 (A0), U2.9 (Q0)
/A1: U1.9 (A1), U2.7 (Q1)
/A2: U1.8 (A2), U2.6 (Q2)
/A3: U1.7 (A3), U2.5 (Q3)
/A4: U1.6 (A4), U2.3 (Q4)
/A5: U1.5 (A5), U2.2 (Q5)
/A6: U1.4 (A6), U2.4 (Q6)
/A7: U1.3 (A7), U2.13 (Q7)
/A8: U1.25 (A8), U2.12 (Q8)
/A9: U1.24 (A9), U2.14 (Q9)
/A10: U1.21 (A10), U2.15 (Q10)
/A11: U1.23 (A11), U2.1 (Q11)
/Addr.Bit.0: C8.1, CON4.26, CON5.31, J1.14
/Addr.Bit.1: C7.1, CON5.29, J1.16
/BinCnt.Clk: U2.10 (CLK), U3.12
/BinCnt.Reset: U2.11 (Reset), U3.2
/Bus.Enable: C6.1, CON4.22, CON5.33, J1.15
/CD.~WE: C5.1, CON4.10, CON5.19, J1.11
/D0: CON4.40, CON5.17, J1.2, U1.11 (D0), U4.18 (O0a)
/D1: CON4.39, CON5.15, J1.3, U1.12 (D1), U4.16 (O1a)
/D2: CON4.38, CON5.13, J1.4, U1.13 (D2), U4.14 (O2a)
/D3: CON4.36, CON5.11, J1.5, U1.15 (D3), U4.12 (O3a)
/D4: CON4.35, CON5.9, J1.6, U1.16 (D4), U4.9 (O0b)
/D5: CON4.34, CON5.7, J1.7, U1.17 (D5), U4.7 (O1b)
/D6: CON4.32, CON5.5, J1.8, U1.18 (D6), U4.5 (O2b)
/D7: CON4.31, CON5.3, J1.9, U1.19 (D7), U4.3 (O3b)
/DMA.Req: CON4.18, CON5.25, U4.17 (I3b)
/EPROM.~CE: J1.12, U1.20 (~CE), U3.13
/EPROM.~OE: C4.1, CON4.12, CON5.21, J1.10, U1.22 (~OE)
/GND: C1.1, C2.2, C3.1, C4.2, C5.2, C6.2, C7.2, C8.2, CON1.2, CON1.3, CON4.1, CON4.3, CON4.4, CON4.5, CON4.6, CON4.7, CON4.8, CON4.9, CON4.11, CON4.13, CON4.15, CON4.17, CON4.19, CON4.21, CON4.23, CON4.25, CON4.27, CON4.29, CON4.30, CON4.33, CON4.37, CON5.2, CON5.4, CON5.6, CON5.8, CON5.10, CON5.12, CON5.14, CON5.16, CON5.18, CON5.20, CON5.22, CON5.24, CON5.26, CON5.28, CON5.30, CON5.32, CON5.34, EC1.2, J1.18, J1.19, J1.20, J1.21, J1.22, J1.23, J1.24, J1.25, S1.1 (A), S2.1 (A), U1.2 (A12), U1.14 (VSS), U2.8 (VSS), U3.7 (GND), U4.6 (I2a), U4.10 (GND), U4.11 (I0b)
/Interrupt: CON4.24, CON5.27, U4.15 (I2b)
/LS244.~OE: J1.13, U4.1 (OEa), U4.19 (OEb)
/Panasonic.D5: CON4.20, U4.13 (I1b)
/Reset: CON4.2, CON5.1, J1.1, U3.1, U4.8 (I3a)
/S1: S1.2 (C), U4.2 (I0a)
/S2: S2.2 (C), U4.4 (I1a)

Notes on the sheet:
CD7 PCB - Front S1 is bridged to set 1 S2 is bridged to set 0 Only C2, U4, CON1, and CON4 are populated on this side CD7 PCB - Back Only the DB25 and the 4 pin PSU ports are populated on this side
Component Notes

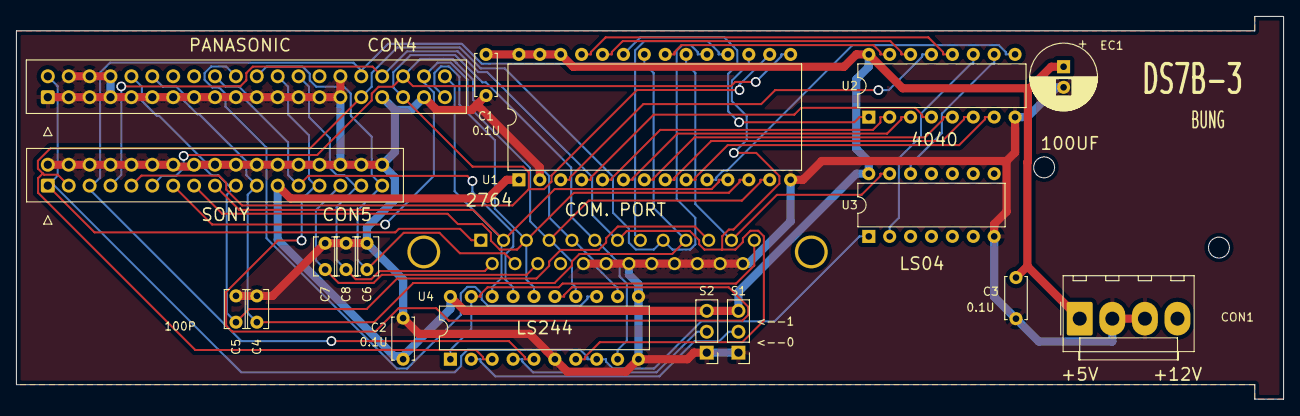
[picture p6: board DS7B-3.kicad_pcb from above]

Board: 2 copper layers, 154.0 x 46.5 mm, 19 parts (1 on the bottom side), 37 nets.

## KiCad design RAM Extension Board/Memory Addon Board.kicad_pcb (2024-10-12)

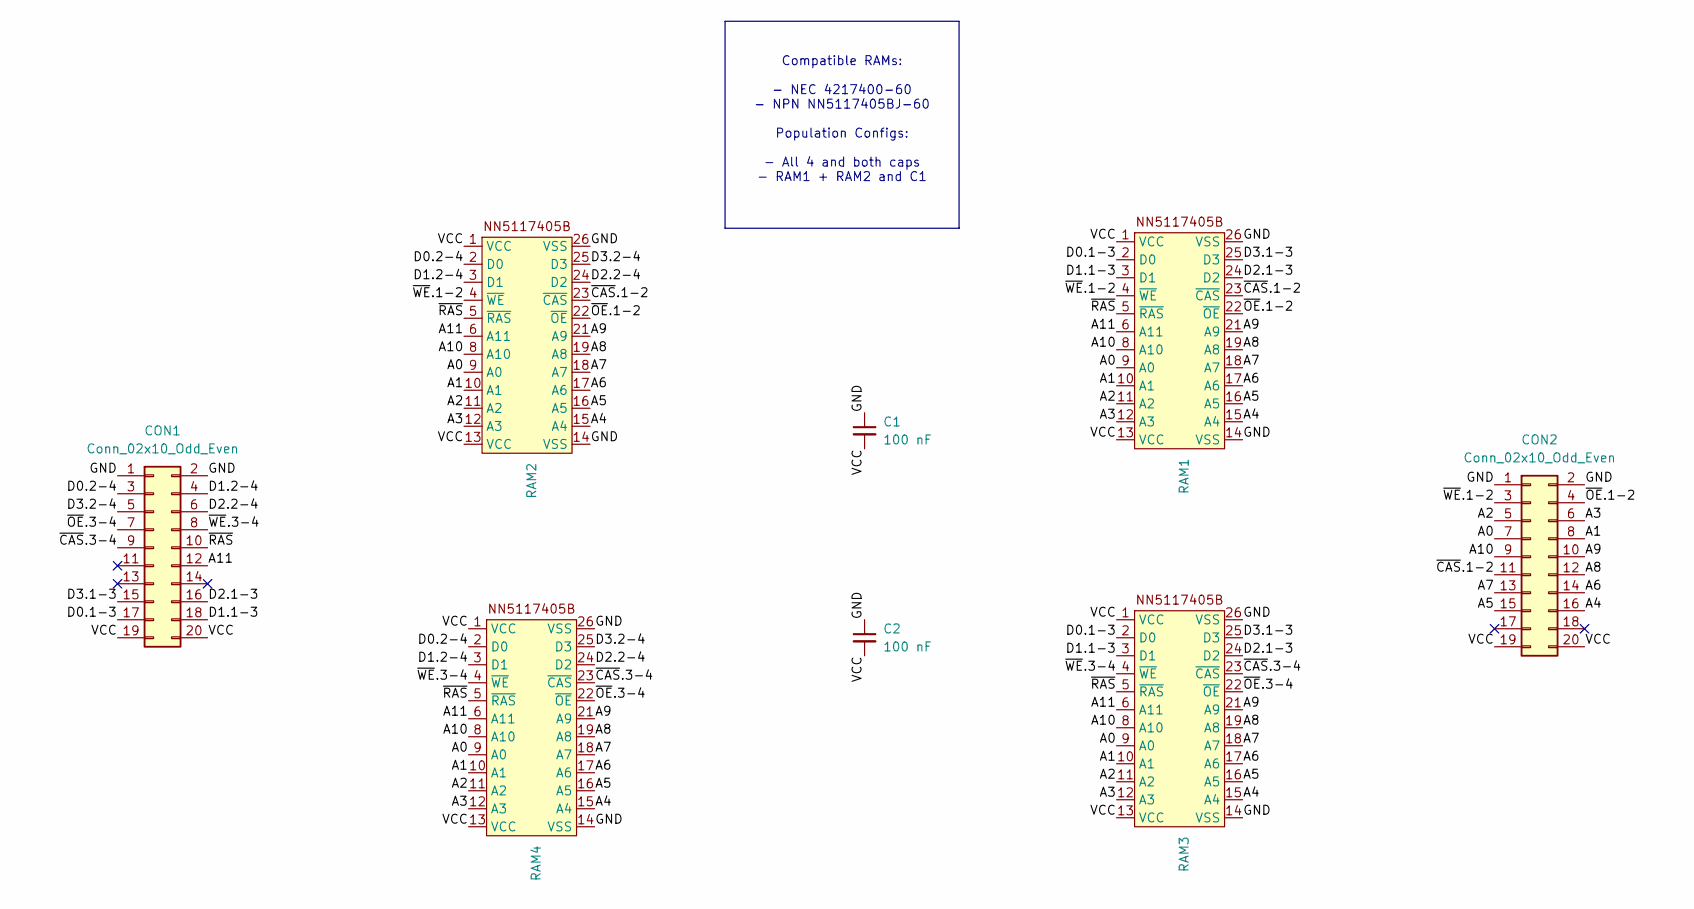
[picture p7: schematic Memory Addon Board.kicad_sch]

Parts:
C1, C2: 100 nF; SMD Passive
CON1, CON2: Conn_02x10_Odd_Even; PinHeader_2x10_P2.54mm_Vertical
RAM1, RAM2, RAM3, RAM4: RAM

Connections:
/A0: CON2.7, RAM1.9 (A0), RAM2.9 (A0), RAM3.9 (A0), RAM4.9 (A0)
/A1: CON2.8, RAM1.10 (A1), RAM2.10 (A1), RAM3.10 (A1), RAM4.10 (A1)
/A2: CON2.5, RAM1.11 (A2), RAM2.11 (A2), RAM3.11 (A2), RAM4.11 (A2)
/A3: CON2.6, RAM1.12 (A3), RAM2.12 (A3), RAM3.12 (A3), RAM4.12 (A3)
/A4: CON2.16, RAM1.15 (A4), RAM2.15 (A4), RAM3.15 (A4), RAM4.15 (A4)
/A5: CON2.15, RAM1.16 (A5), RAM2.16 (A5), RAM3.16 (A5), RAM4.16 (A5)
/A6: CON2.14, RAM1.17 (A6), RAM2.17 (A6), RAM3.17 (A6), RAM4.17 (A6)
/A7: CON2.13, RAM1.18 (A7), RAM2.18 (A7), RAM3.18 (A7), RAM4.18 (A7)
/A8: CON2.12, RAM1.19 (A8), RAM2.19 (A8), RAM3.19 (A8), RAM4.19 (A8)
/A9: CON2.10, RAM1.21 (A9), RAM2.21 (A9), RAM3.21 (A9), RAM4.21 (A9)
/A10: CON2.9, RAM1.8 (A10), RAM2.8 (A10), RAM3.8 (A10), RAM4.8 (A10)
/A11: CON1.12, RAM1.6 (A11), RAM2.6 (A11), RAM3.6 (A11), RAM4.6 (A11)
/D0.1-3: CON1.17, RAM1.2 (D0), RAM3.2 (D0)
/D0.2-4: CON1.3, RAM2.2 (D0), RAM4.2 (D0)
/D1.1-3: CON1.18, RAM1.3 (D1), RAM3.3 (D1)
/D1.2-4: CON1.4, RAM2.3 (D1), RAM4.3 (D1)
/D2.1-3: CON1.16, RAM1.24 (D2), RAM3.24 (D2)
/D2.2-4: CON1.6, RAM2.24 (D2), RAM4.24 (D2)
/D3.1-3: CON1.15, RAM1.25 (D3), RAM3.25 (D3)
/D3.2-4: CON1.5, RAM2.25 (D3), RAM4.25 (D3)
/GND: C1.1, C2.1, CON1.1, CON1.2, CON2.1, CON2.2, RAM1.14 (VSS), RAM1.26 (VSS), RAM2.14 (VSS), RAM2.26 (VSS), RAM3.14 (VSS), RAM3.26 (VSS), RAM4.14 (VSS), RAM4.26 (VSS)
/VCC: C1.2, C2.2, CON1.19, CON1.20, CON2.19, CON2.20, RAM1.1 (VCC), RAM1.13 (VCC), RAM2.1 (VCC), RAM2.13 (VCC), RAM3.1 (VCC), RAM3.13 (VCC), RAM4.1 (VCC), RAM4.13 (VCC)
/~CAS.1-2: CON2.11, RAM1.23 (~CAS), RAM2.23 (~CAS)
/~CAS.3-4: CON1.9, RAM3.23 (~CAS), RAM4.23 (~CAS)
/~OE.1-2: CON2.4, RAM1.22 (~OE), RAM2.22 (~OE)
/~OE.3-4: CON1.7, RAM3.22 (~OE), RAM4.22 (~OE)
/~RAS: CON1.10, RAM1.5 (~RAS), RAM2.5 (~RAS), RAM3.5 (~RAS), RAM4.5 (~RAS)
/~WE.1-2: CON2.3, RAM1.4 (~WE), RAM2.4 (~WE)
/~WE.3-4: CON1.8, RAM3.4 (~WE), RAM4.4 (~WE)

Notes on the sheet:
Compatible RAMs: - NEC 4217400-60 - NPN NN5117405BJ-60 Population Configs: - All 4 and both caps - RAM1 + RAM2 and C1

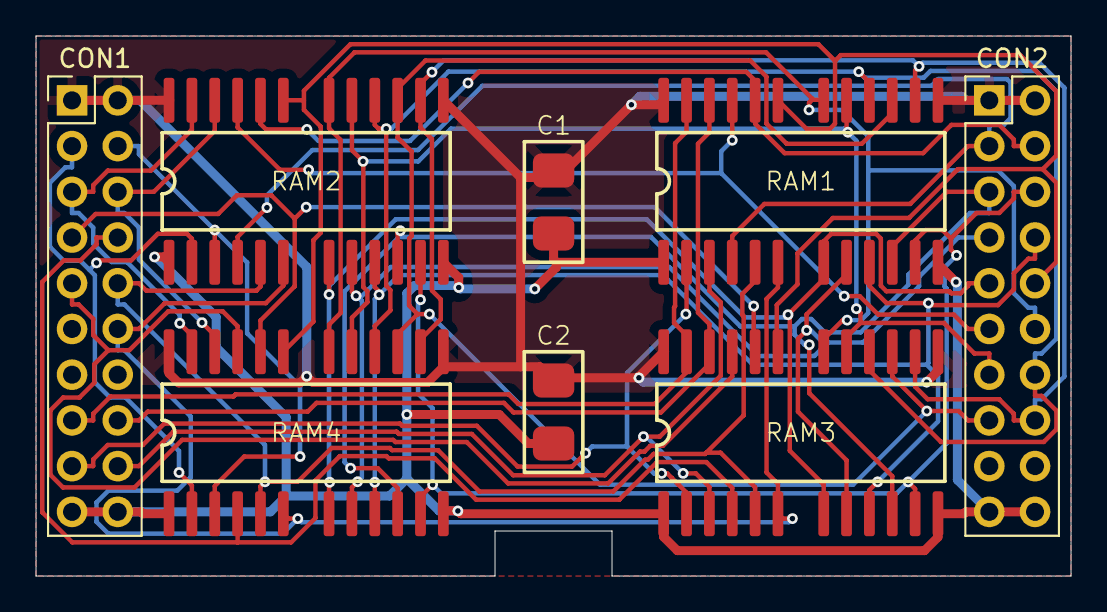
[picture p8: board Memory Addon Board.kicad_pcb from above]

Board: 2 copper layers, 57.5 x 30.0 mm, 8 parts (0 on the bottom side), 29 nets.

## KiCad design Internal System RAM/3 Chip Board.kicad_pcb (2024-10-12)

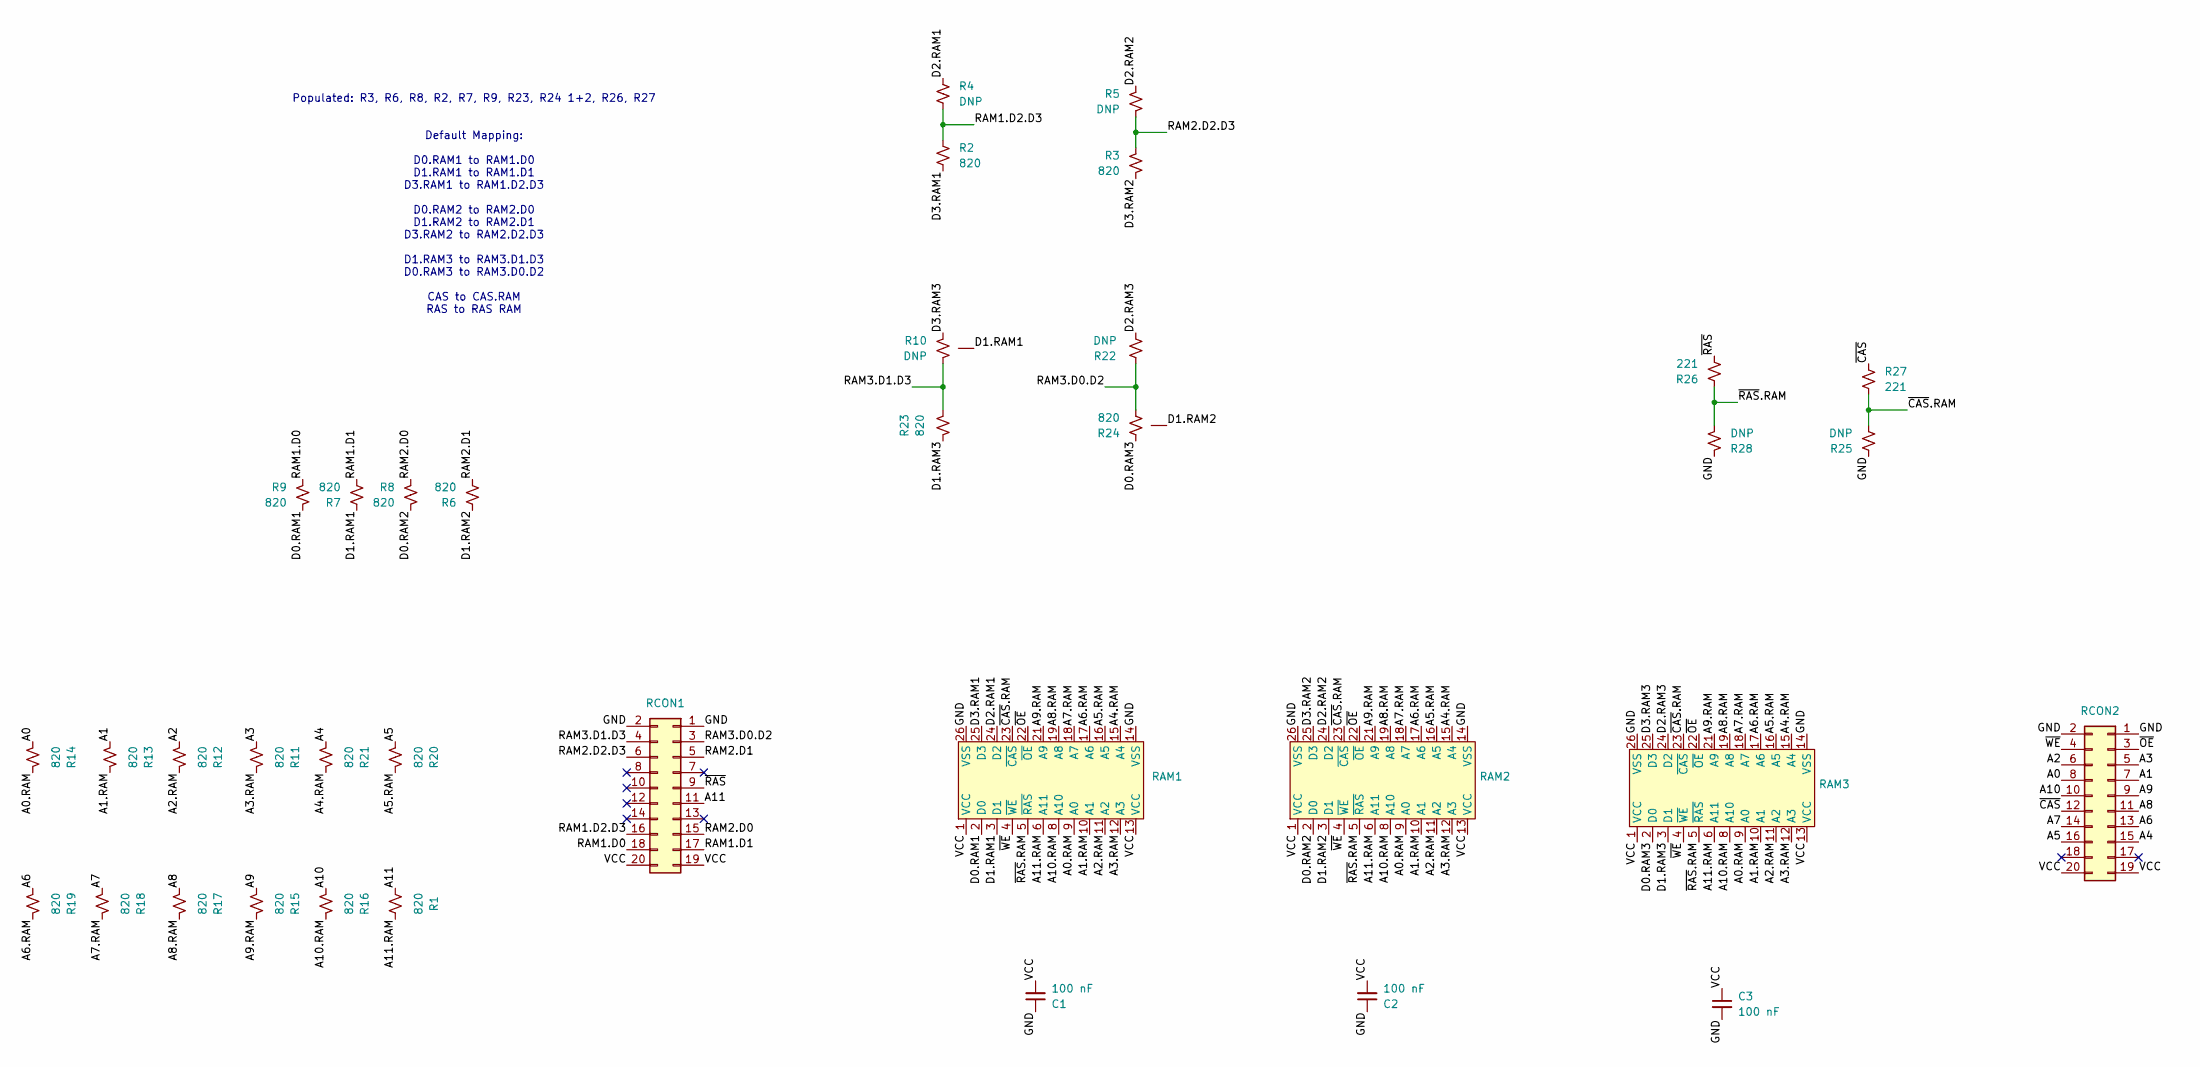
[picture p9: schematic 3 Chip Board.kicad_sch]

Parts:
C1, C2, C3: 100 nF; SMD C
R1, R2, R3, R6, R7, R8, R9, R11, R12, R13, R14, R15, R16, R17, R18, R19, R20, R21, R23: 820; SMD R
R4, R5, R22, R25, R28: DNP; SMD R
R10: DNP; SMD R3
R24: 820; SMD R3
R26, R27: 221; SMD R
RAM1, RAM2, RAM3: RAM
RCON1, RCON2: Conn_02x10_Odd_Even; PinSocket_2x10_P2.54mm_Vertical

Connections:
/A0: R14.2, RCON2.8
/A0.RAM: R14.1, RAM1.9 (A0), RAM2.9 (A0), RAM3.9 (A0)
/A1: R13.2, RCON2.7
/A1.RAM: R13.1, RAM1.10 (A1), RAM2.10 (A1), RAM3.10 (A1)
/A2: R12.2, RCON2.6
/A2.RAM: R12.1, RAM1.11 (A2), RAM2.11 (A2), RAM3.11 (A2)
/A3: R11.2, RCON2.5
/A3.RAM: R11.1, RAM1.12 (A3), RAM2.12 (A3), RAM3.12 (A3)
/A4: R21.2, RCON2.15
/A4.RAM: R21.1, RAM1.15 (A4), RAM2.15 (A4), RAM3.15 (A4)
/A5: R20.2, RCON2.16
/A5.RAM: R20.1, RAM1.16 (A5), RAM2.16 (A5), RAM3.16 (A5)
/A6: R19.2, RCON2.13
/A6.RAM: R19.1, RAM1.17 (A6), RAM2.17 (A6), RAM3.17 (A6)
/A7: R18.2, RCON2.14
/A7.RAM: R18.1, RAM1.18 (A7), RAM2.18 (A7), RAM3.18 (A7)
/A8: R17.2, RCON2.11
/A8.RAM: R17.1, RAM1.19 (A8), RAM2.19 (A8), RAM3.19 (A8)
/A9: R15.2, RCON2.9
/A9.RAM: R15.1, RAM1.21 (A9), RAM2.21 (A9), RAM3.21 (A9)
/A10: R16.2, RCON2.10
/A10.RAM: R16.1, RAM1.8 (A10), RAM2.8 (A10), RAM3.8 (A10)
/A11: R1.1, RCON1.11
/A11.RAM: R1.2, RAM1.6 (A11), RAM2.6 (A11), RAM3.6 (A11)
/D0.RAM1: R9.2, RAM1.2 (D0)
/D0.RAM2: R8.2, RAM2.2 (D0)
/D0.RAM3: R24.1, RAM3.2 (D0)
/D1.RAM1: R7.1, R10.3 (Pad_3), RAM1.3 (D1)
/D1.RAM2: R6.1, R24.3 (Pad_3), RAM2.3 (D1)
/D1.RAM3: R23.2, RAM3.3 (D1)
/D2.RAM1: R4.2, RAM1.24 (D2)
/D2.RAM2: R5.2, RAM2.24 (D2)
/D2.RAM3: R22.1, RAM3.24 (D2)
/D3.RAM1: R2.2, RAM1.25 (D3)
/D3.RAM2: R3.2, RAM2.25 (D3)
/D3.RAM3: R10.1, RAM3.25 (D3)
/GND: C1.1, C2.1, C3.2, R25.2, R28.2, RAM1.14 (VSS), RAM1.26 (VSS), RAM2.14 (VSS), RAM2.26 (VSS), RAM3.14 (VSS), RAM3.26 (VSS), RCON1.1, RCON1.2, RCON2.1, RCON2.2
/RAM1.D0: R9.1, RCON1.18
/RAM1.D1: R7.2, RCON1.17
/RAM1.D2.D3: R2.1, R4.1, RCON1.16
/RAM2.D0: R8.1, RCON1.15
/RAM2.D1: R6.2, RCON1.5
/RAM2.D2.D3: R3.1, R5.1, RCON1.6
/RAM3.D0.D2: R22.2, R24.2, RCON1.3
/RAM3.D1.D3: R10.2, R23.1, RCON1.4
/VCC: C1.2, C2.2, C3.1, RAM1.1 (VCC), RAM1.13 (VCC), RAM2.1 (VCC), RAM2.13 (VCC), RAM3.1 (VCC), RAM3.13 (VCC), RCON1.19, RCON1.20, RCON2.19, RCON2.20
/~CAS: R27.1, RCON2.12
/~CAS.RAM: R25.1, R27.2, RAM1.23 (~CAS), RAM2.23 (~CAS), RAM3.23 (~CAS)
/~OE: RAM1.22 (~OE), RAM2.22 (~OE), RAM3.22 (~OE), RCON2.3
/~RAS: R26.2, RCON1.9
/~RAS.RAM: R26.1, R28.1, RAM1.5 (~RAS), RAM2.5 (~RAS), RAM3.5 (~RAS)
/~WE: RAM1.4 (~WE), RAM2.4 (~WE), RAM3.4 (~WE), RCON2.4

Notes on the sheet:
Populated: R3, R6, R8, R2, R7, R9, R23, R24 1+2, R26, R27 Default Mapping: D0.RAM1 to RAM1.D0 D1.RAM1 to RAM1.D1 D3.RAM1 to RAM1.D2.D3 D0.RAM2 to RAM2.D0 D1.RAM2 to RAM2.D1 D3.RAM2 to RAM2.D2.D3 D1.RAM3 to RAM3.D1.D3 D0.RAM3 to RAM3.D0.D2 CAS to CAS.RAM RAS to RAS RAM

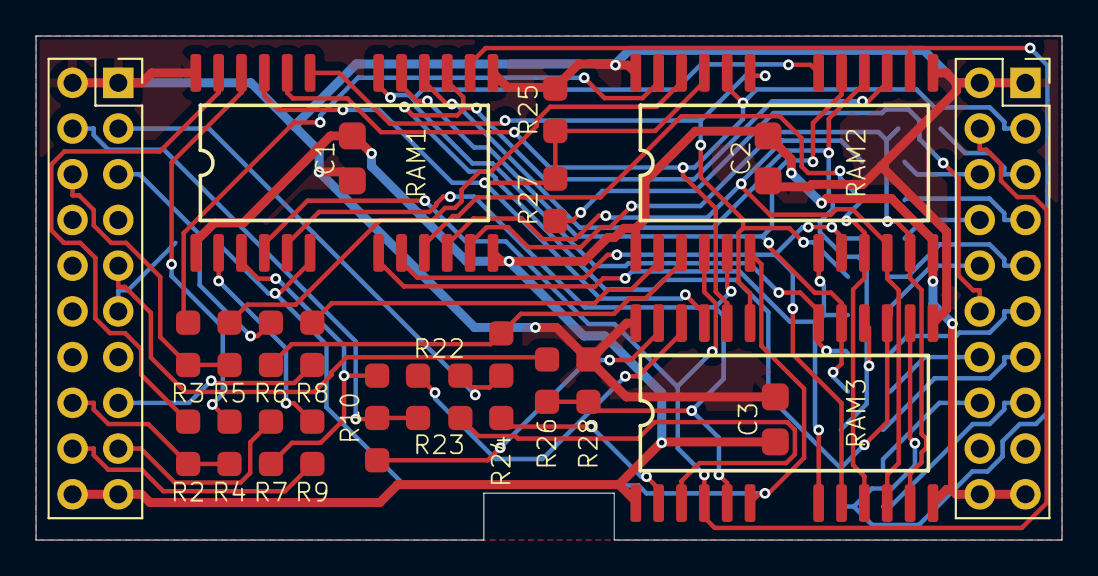
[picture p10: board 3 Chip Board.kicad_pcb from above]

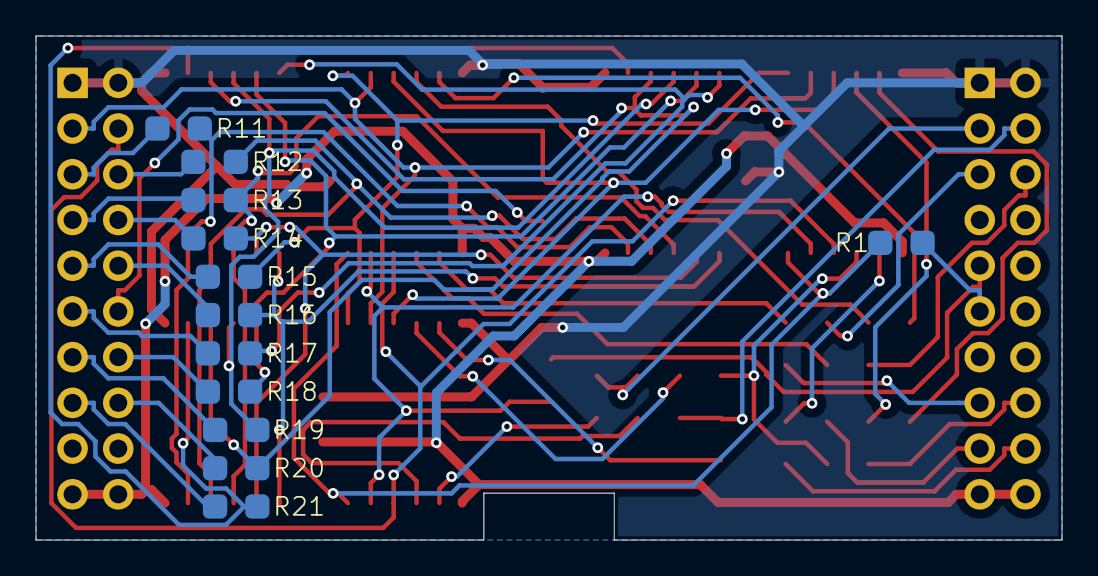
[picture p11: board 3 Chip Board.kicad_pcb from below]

Board: 2 copper layers, 57.0 x 28.0 mm, 36 parts (12 on the bottom side), 52 nets.
